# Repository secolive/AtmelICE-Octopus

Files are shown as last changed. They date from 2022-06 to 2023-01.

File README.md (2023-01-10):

"Octopus" adapter for Atmel-ICE
===============================

Introduction
------------

this project provides KiCad files for the implementation of an adapter board for use with the Atmel-ICE JTAG debugger.
It provides the following features:

- 0.1" headers with standard pinouts
- Specific VCCIO connector for using a probe
- Jumpers to select VCCIO from the appropriate connectors depending on the use case
- VCCIO comparator and limiter for current nominal voltages: 1.8V, 2.5V, 3.0V, 3.3V, 3.7V, 5.0V
- Voltage boosting to power the LEDs when VCCIO voltages below 3.3V are used

### Motivation

The Atmel-ICE provides two 0.05" headers, for which it's unfortunately difficult to get the appropriate cables. Some
versions of the Atmel-ICE come with a "squid" adapter, but are significantly more expensive.

Boards
------

This project contains two different boards that will assemble and work together as a single "product":

- ATMEL-ICE-Octopus: this is the main adapter board, including all circuits implementing VCCIO selection and limiting

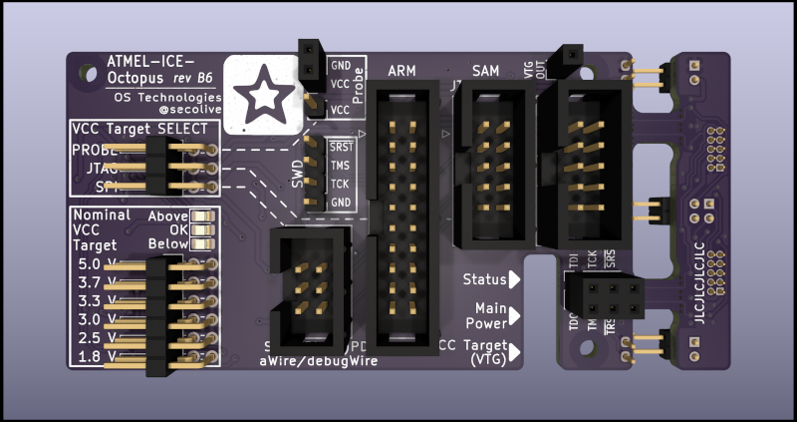
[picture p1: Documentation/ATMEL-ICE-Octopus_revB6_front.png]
Octopus front view
  
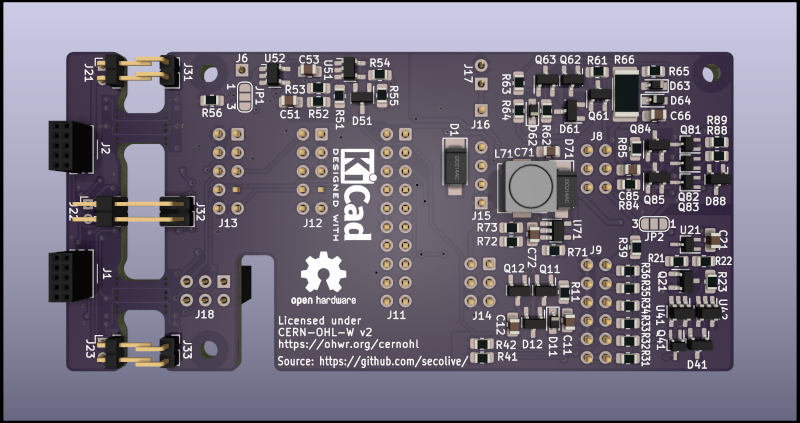
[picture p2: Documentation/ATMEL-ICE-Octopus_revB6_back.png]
Octopus front view
  

- JTAG-MINI_ADAPTER: 0.1" to 0.05" adapter for standard 10-pin JTAG connectors

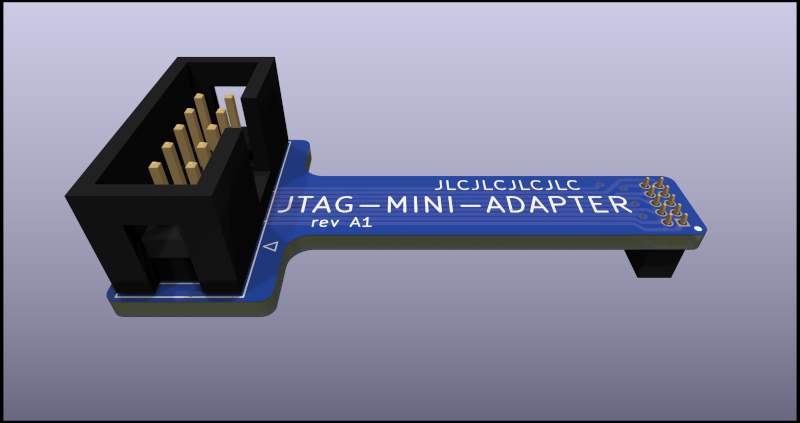
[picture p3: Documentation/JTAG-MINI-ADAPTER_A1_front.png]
JTAG Mini Adapter
  

Connectors
----------

The following connectors are provided by the Octopus:
- J11: 20-pin 0.1" Multi-ICE JTAG header
- J12: 10-pin 0.1" JTAG connector for ARM
- J13: 10-pin 0.1" JTAG connector for Atmel AVR
- J14: 6-pin 0.1" connector for misc AVR protocols: SPI, debugWire, aWire, PDI, UPDI, TPI
- J15: 4-pin 0.1" header matching Arduino's SWD port
- J16: 1-pin 0.1" header to use as VCCIO probe, typically in conjunction with J15 which does not provide any VCCIO;
  note that J15&J16 together work as a 6-pin 0.1" header combining SWD with VCCIO probe
- J17: 2-pin 0.1" socket to be used for adhoc connections
- J18: 6-pin 0.1" socket to be used for adhoc connections
- J6: 1-pin 0.1" socket to be used as a test point for the VTG provided to Atmel-ICE

VCCIO
-----

The Atmel-ICE needs to be fed with the VCCIO corresponding to the board under test, so that it will work at the same
logic level as the CPU being inspected.

To avoid damage to your CPU, it is important that the VCCIO that the Atmel-ICE uses does not exceed the level actually
used by the board. The octopus helps providing safety as follows:

- The reference VCCIO voltage can come from one of three sources, depending on your use case; these sources are: the
  JTAG connectors, the AVR misc connector, and the VCCIO probe. Use the appropriate source depending in your use case
  to ensure that you're using the VCCIO that matches the component you're connecting to.

- Select the appropriate source using the corresponding jumper; common use cases are:
    * when using a JTAG cable: put the jumper in the JTAG position;
    * when using the AVR misc cable, and your board runs on 5.0V: put the jumper in the SPI position;
    * when using the AVR misc cable, and your board runs on something else than 5.0V: put the jumper in the PROBE
      position, and use the PROBE connector in addition to the SPI cable;
    * when using the SWD cable: put the jumper in the PROBE position, and use the PROBE connector in addition to the SPI
      cable.

- You need to further configure the nominal voltage you're expecting to use with your device, using the appropriate
  jumper. The on-board detection logic will use this configuration to decide whether it is safe to propagate the VCCIO
  voltage to the Atmel-ICE VTG input, as follows:
    * if the input VCCIO matches the nominal voltage range, it is send to the Atmel-ICE, and the green "OK" LED will
      be lit;
    * if the input VCCIO is below the nominal voltage range, it is send to the Atmel-ICE nevertheless, but the amber
      "Below" LED will be lit;
    * otherwise, i.e. if the input VCCIO is above the nominal voltage range, no voltage is sent to the Atmel-ICE, because
      it is considered as a fault which could result in using a voltage higher than the expected VCCIO of the target
      device. In this case, the red "Above" LED will be lit.

Simplified Variants
-------------------

Depending on your use cases, you might not need all the features of the board; for example, perhaps you  need only the
various 0.1" connectors, but don't care about the voltage limiting. Reducing the feature set enables you to skip some
components and hence reduce the cost. Three features are optional:

- VCCIO monitoring and limiting; this main feature can by bypassed altogether, and the selected VCCIO can be sent
  directly as VTG to the Atmel-ICE. You will then have to ensure that you select the proper VCCIO signal, and that it
  does not exceed the target device voltage.

- Status output of the VCCIO monitoring and limiting; obviously, if you don't perform any monitoring and limiting, you
  won't need any status LEDs. Note that it's technically possible to have some voltage monitoring, without limiting,
  meaning VCCIO will always be sent as VTG to the Atmel-ICE, but the Above/OK/Below LEDs will still indicate whether the
  voltage is in the intended range.

- Voltage boosting to power LEDs when input voltage is below 3.3V. Obviously, if you don't want any status LEDs, you
  don't need any voltage boosting.

Altogether, this means the following variants are possible:

- Variant 1a: VCCIO limiting, monitoring with LEDS, voltage boosting
- Variant 1b: VCCIO limiting, monitoring with LEDS, no voltage boosting
- Variant 2a: VCCIO monitoring with LEDs, no limiting, voltage boosting
- Variant 2b: VCCIO monitoring with LEDs, no limiting, no voltage boosting
- Variant 3: VCCIO limiting, no monitoring, no LEDs
- Variant 4: no VCCIO limiting, no monitoring, no LEDs

The following table describes, for which variant, which components can be skipped, and how to position the solder
jumpers JP1 and JP2.

| Variant | *10-*39 | *40-*49 | *50-*59 | *60-*79 | *80-*89 | JP1 2-3 | JP2 2-3 |
|---|---|---|---|---|---|---|---|
| 1a | | | | | | | |
| 1b | | | |  skip | | | X |
| 2a | skip Q12, C12 | |  skip | | | X | |
| 2b | skip Q12, C12 | |  skip |  skip | | X | X |
| 3 | | skip Q41, R41, *42 | |  skip |  skip | | |
| 4 | skip | skip |  skip |  skip |  skip | X | |

Note that wildcards are used to designate any component with the given number, and when ranges are provided, any
component of any type within the given number range should be skipped. The JP columns indicate when the corresponding
jumper needs to have its pads 2 and 3 bridged.

Regarding JP1 and JP2, note that by default they are always bridged in the 1-2 position. It is not necessary to cut this
traced bridging, as long as the corresponding components are skipped according to the table above.

!! Do not forget to verify the proper jumper settings when adding new components to the board, e.g. in a later stage !!

Assembling
----------

The main board is composed of two different parts; when looking at the front:
- the right-hand side contains the black plate, which is meant to be connected to the Atmel-ICE
- the main part is the squid adapter itself

The back plate can be separated from the main part by breaking off the two break tabs. Connect the back plate to the 
main plate using angled 2mm-pitch headers. 

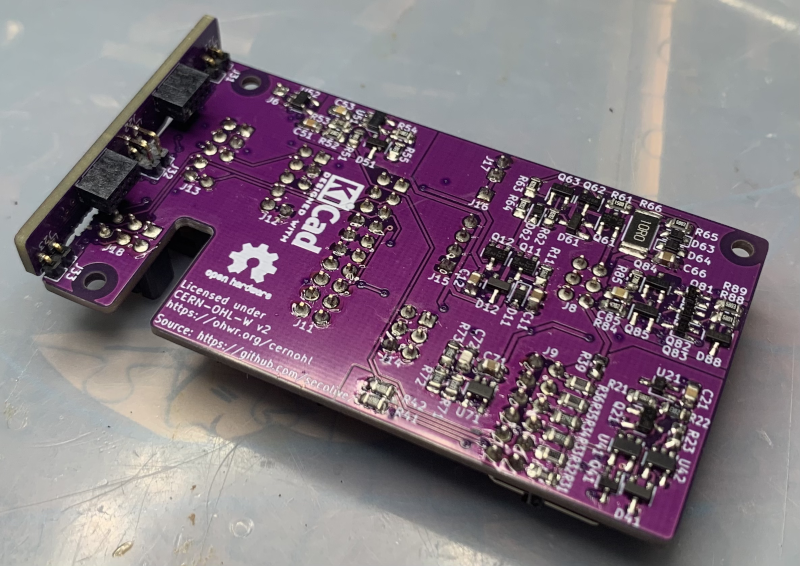
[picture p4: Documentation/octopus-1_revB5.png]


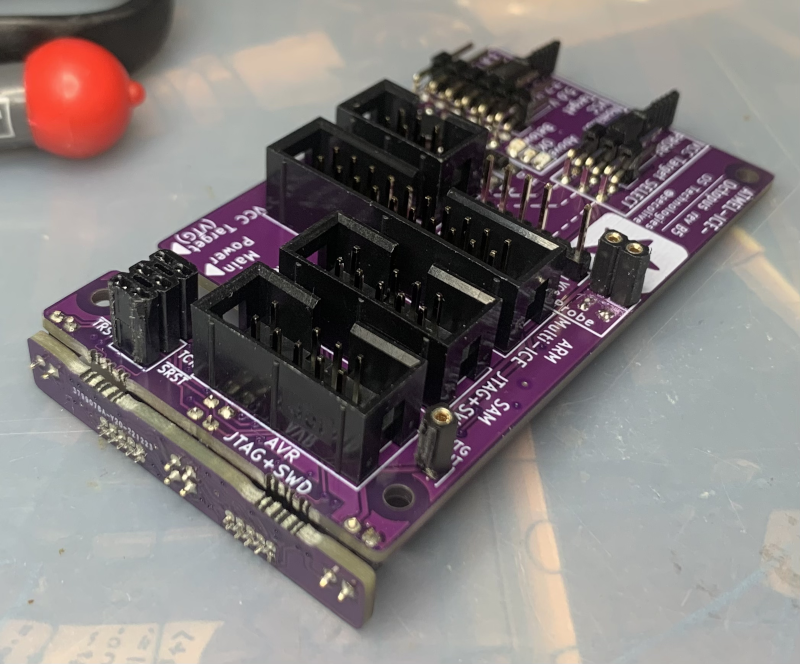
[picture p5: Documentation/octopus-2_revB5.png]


The assembled octopus adapter can then be plugged atop the Atmel-ICE; both products can be assembled using 8mm-long
spacers using M2.5 threads and screws (plastic recommended), as follows:

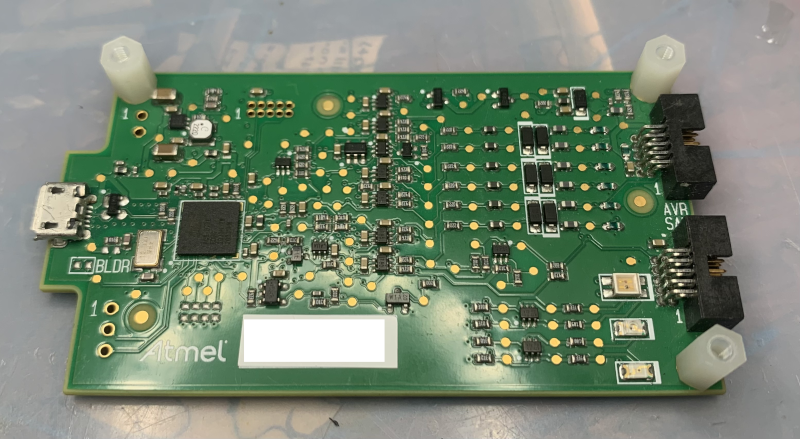
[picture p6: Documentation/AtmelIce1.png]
Atmel-ICE with M2.5x8mm spacers


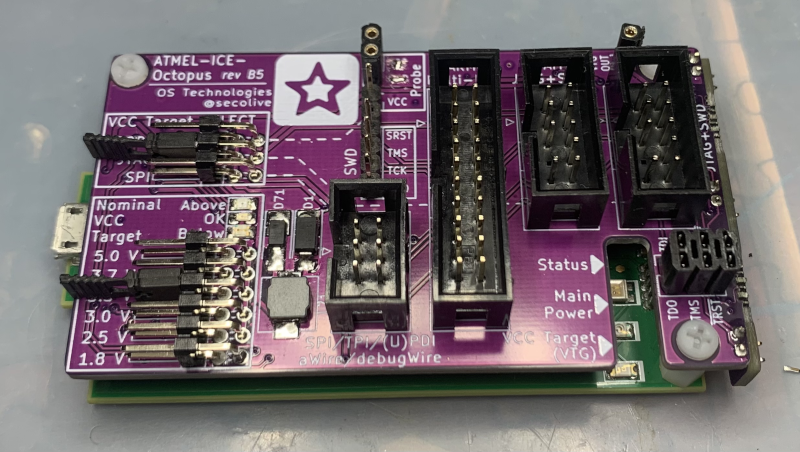
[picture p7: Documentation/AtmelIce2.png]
Atmel-ICE with Octopus installed


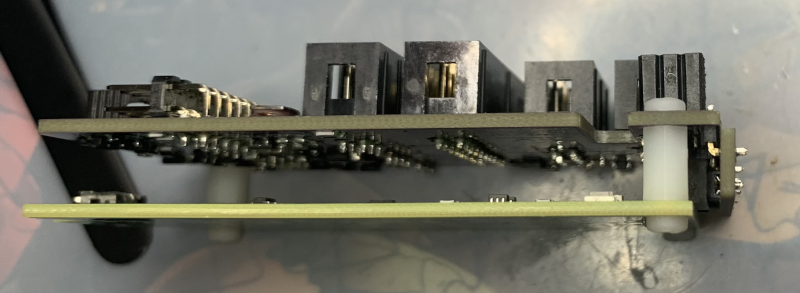
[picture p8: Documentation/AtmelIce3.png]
Atmel-ICE with Octopus installed


On the target device, use the adapter when using a standard Atmel 0.05" header; the adapter is designed to fit an
Arduino Due board and not collide with a shield, as follows:

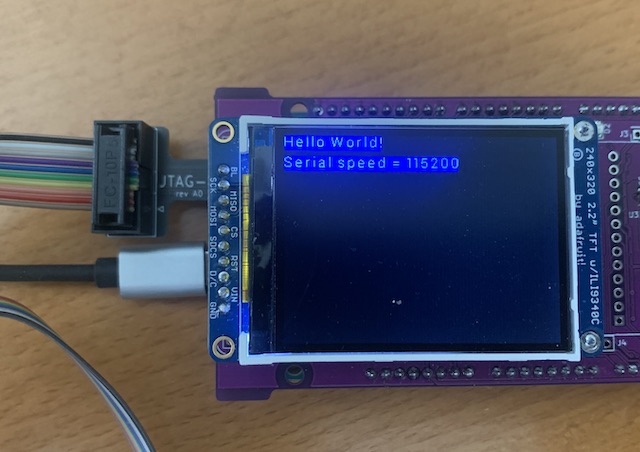
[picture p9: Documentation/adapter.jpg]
JTAG Adapter


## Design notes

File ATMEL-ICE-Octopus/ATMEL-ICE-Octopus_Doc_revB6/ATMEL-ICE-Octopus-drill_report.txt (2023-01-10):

Drill report for ATMEL-ICE-Octopus.kicad_pcb
Created on Monday, 09 January 2023 at 15:38:07

Copper Layer Stackup:
    =============================================================
    L1 :  F.Cu                      front
    L2 :  B.Cu                      back

Drill file 'ATMEL-ICE-Octopus.drl' contains
    plated through holes:
    =============================================================
    T1  0.400mm  0.0157"  (111 holes)
    T2  0.700mm  0.0276"  (20 holes)
    T3  0.800mm  0.0315"  (16 holes)
    T4  1.000mm  0.0394"  (76 holes)

    Total plated holes count 223

Not plated through holes are merged with plated holes
    unplated through holes:
    =============================================================
    T5  0.500mm  0.0197"  (24 holes)
    T6  2.500mm  0.0984"  (3 holes)

    Total unplated holes count 27

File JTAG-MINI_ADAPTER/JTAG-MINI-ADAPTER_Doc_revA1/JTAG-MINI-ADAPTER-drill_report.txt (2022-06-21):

Drill report for JTAG-MINI-ADAPTER.kicad_pcb
Created on Tuesday, 21 June 2022 at 16:49:53

Copper Layer Stackup:
    =============================================================
    L1 :  F.Cu                      front
    L2 :  B.Cu                      back

Drill file 'JTAG-MINI-ADAPTER.drl' contains
    plated through holes:
    =============================================================
    T1  0.400mm  0.0157"  (5 holes)
    T2  0.700mm  0.0276"  (10 holes)
    T3  1.000mm  0.0394"  (9 holes)

    Total plated holes count 24

Not plated through holes are merged with plated holes
    unplated through holes:
    =============================================================

    Total unplated holes count 0

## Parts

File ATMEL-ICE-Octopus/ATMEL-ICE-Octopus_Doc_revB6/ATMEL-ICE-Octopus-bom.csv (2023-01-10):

Row | Part | Footprint | Value | References | Quantity Per PCB | Description | Status
1 | C_Small | C_0805_2012Metric_Pad1.18x1.45mm_HandSolder | 10 pF | C72 | 1 | Unpolarized capacitor, small symbol
2 | C_Small | C_0805_2012Metric_Pad1.18x1.45mm_HandSolder | 1 nF | C53 C85 | 2 | Unpolarized capacitor, small symbol
3 | C_Small | C_0805_2012Metric_Pad1.18x1.45mm_HandSolder | 2.2 nF | C21 | 1 | Unpolarized capacitor, small symbol
4 | C_Small | C_0805_2012Metric_Pad1.18x1.45mm_HandSolder | 33 nF | C51 | 1 | Unpolarized capacitor, small symbol
5 | C_Small | C_0805_2012Metric_Pad1.18x1.45mm_HandSolder | 1 µF | C11 C66 C71 | 3 | Unpolarized capacitor, small symbol
6 | C_Small | C_0805_2012Metric_Pad1.18x1.45mm_HandSolder | 2.2 µF | C12 | 1 | Unpolarized capacitor, small symbol
7 | LED | LED_0805_2012Metric_Pad1.15x1.40mm_HandSolder | AMBER | D83 | 1 | Light emitting diode
8 | BAT54A | SOT-23_Handsoldering | BAT54A | D88 | 1 | schottky barrier diode
9 | BAT54C | SOT-23_Handsoldering | BAT54C | D12 D41 D51 | 3 | dual schottky barrier diode, common cathode
10 | BAT54S | SOT-23_Handsoldering | BAT54S | D61 | 1 | schottky barrier diode
11 | LED | LED_0805_2012Metric_Pad1.15x1.40mm_HandSolder | GREEN | D82 | 1 | Light emitting diode
12 | Zener_SOD323 | D_SOD-323_HandSoldering | PZU5.6B2A | D11 D62 D63 D64 | 4 | Zener diode
13 | LED | LED_0805_2012Metric_Pad1.15x1.40mm_HandSolder | RED | D81 | 1 | Light emitting diode
14 | D | D_SMA+SMP_Handsoldering | SMAJ13A | D1 | 1 | Diode
15 | D_Schottky | D_SMA+SMP_Handsoldering | SS13 | D71 | 1 | Schottky diode
16 | Conn_01x01_Female | PinSocket_1x01_P2.54mm_Vertical | Conn_01x01_Female | J6 | 1 | Generic connector, single row, 01x01, script generated (kicad-library-utils/schlib/autogen/connector/)
17 | Conn_01x02 | PinHeader_1x02_P2.00mm_Horizontal | Conn_01x02_Angled | J21 J23 | 2 | Generic connector, single row, 01x02, script generated (kicad-library-utils/schlib/autogen/connector/)
18 | Conn_01x02 | PinHeader_1x02_P2.00mm_Angled | Conn_01x02_Angled | J31 J33 | 2 | Generic connector, single row, 01x02, script generated (kicad-library-utils/schlib/autogen/connector/)
19 | Conn_01x02_Female | PinSocket_1x02_P2.54mm_Vertical | Conn_01x02_Female | J17 | 1 | Generic connector, single row, 01x02, script generated (kicad-library-utils/schlib/autogen/connector/)
20 | Conn_01x04 | PinHeader_2x02_P2.00mm_Horizontal | Conn_02x02_Angled | J22 | 1 | Generic connector, single row, 01x04, script generated (kicad-library-utils/schlib/autogen/connector/)
21 | Conn_01x04 | PinHeader_2x02_P2.00mm_Angled | Conn_02x02_Angled | J32 | 1 | Generic connector, single row, 01x04, script generated (kicad-library-utils/schlib/autogen/connector/)
22 | Conn_01x01 | PinHeader_1x01_P2.54mm_Vertical | conn_01x01 | J16 | 1 | Generic connector, single row, 01x01, script generated (kicad-library-utils/schlib/autogen/connector/)
23 | Conn_01x04 | PinHeader_1x04_P2.54mm_Vertical | conn_01x04 | J15 | 1 | Generic connector, single row, 01x04, script generated (kicad-library-utils/schlib/autogen/connector/)
24 | Conn_02x03_Odd_Even | IDC-Header_2x03_P2.54mm_Vertical | conn_02x03 | J14 | 1 | Generic connector, double row, 02x03, odd/even pin numbering scheme (row 1 odd numbers, row 2 even numbers), script generated (kicad-library-utils/schlib/autogen/connector/)
25 | Conn_02x03_Odd_Even | PinSocket_2x03_P2.54mm_Vertical | conn_02x03_Female | J18 | 1 | Generic connector, double row, 02x03, odd/even pin numbering scheme (row 1 odd numbers, row 2 even numbers), script generated (kicad-library-utils/schlib/autogen/connector/)
26 | Conn_02x05_Odd_Even | PinSocket_2x05_P1.27mm_Vertical_AtmelICE_WithTab | conn_02x05 | J1 J2 | 2 | Generic connector, double row, 02x05, odd/even pin numbering scheme (row 1 odd numbers, row 2 even numbers), script generated (kicad-library-utils/schlib/autogen/connector/)
27 | Conn_JTAG_02x05 | IDC-Header_2x05_P2.54mm_Vertical_Key7 | conn_02x05_key7 | J12 J13 | 2 | Generic connector, double row, 02x05, odd/even pin numbering scheme (row 1 odd numbers, row 2 even numbers), script generated (kicad-library-utils/schlib/autogen/connector/)
28 | Conn_02x10_Odd_Even | IDC-Header_2x10_P2.54mm_Vertical | conn_02x10 | J11 | 1 | Generic connector, double row, 02x10, odd/even pin numbering scheme (row 1 odd numbers, row 2 even numbers), script generated (kicad-library-utils/schlib/autogen/connector/)
29 | Conn_02x03_Odd_Even | PinHeader_2x03_P2.54mm_Horizontal_Jumper | ~ | J8 | 1 | Generic connector, double row, 02x03, odd/even pin numbering scheme (row 1 odd numbers, row 2 even numbers), script generated (kicad-library-utils/schlib/autogen/connector/)
30 | Conn_02x06_Odd_Even | PinHeader_2x06_P2.54mm_Horizontal_Jumper | ~ | J9 | 1 | Generic connector, double row, 02x06, odd/even pin numbering scheme (row 1 odd numbers, row 2 even numbers), script generated (kicad-library-utils/schlib/autogen/connector/)
31 | L_Small | L_6.5x6.5_H4.5 | LQH5BPN100MT0L | L71 | 1 | Inductor, small symbol
32 | 2SK2394 | SOT-23_Handsoldering | 2SK2394 | Q21 | 1 | N-JFET transistor, 15 V, 10 to 20 mA, 38 mS, -0.3 to -1.0 Vgs(off), SOT23-3
33 | BC857B | SOT-23_Handsoldering | BC857B | Q63 Q84 Q85 | 3 | 500mA Ic, 60V Vce, PNP Transistor, SOT-23
34 | CPH3910 | SOT-23_Handsoldering | CPH3910 | Q11 Q12 Q61 | 3 | N-JFET transistor, 25 V, 20 to 40 mA, 40 mS, -0.6 to -1.8 Vgs(off), SOT23-3
35 | NX6008NBKW | SOT-323_SC-70_Handsoldering | NX6008NBKW | Q41 Q81 Q82 Q83 | 4 | 60V Vds, 0.9V Vgs(th) max, 250mA Id, N-Channel MOSFET, SOT-323
36 | NXV100XP | SOT-23_Handsoldering | NXV100XP | Q62 | 1 | P-channel MOSFET -30V, -1.5A
37 | R | R_2512_6332Metric_Pad1.40x3.35mm_HandSolder | 10 Ω | R66 | 1 | Resistor
38 | R | R_0805_2012Metric_Pad1.20x1.40mm_HandSolder | 150 Ω | R61 | 1 | Resistor
39 | R | R_0805_2012Metric_Pad1.20x1.40mm_HandSolder | 280 Ω | R85 | 1 | Resistor
40 | R | R_0805_2012Metric_Pad1.20x1.40mm_HandSolder | 560 Ω | R11 | 1 | Resistor
41 | R | R_0805_2012Metric_Pad1.20x1.40mm_HandSolder | 6.8 kΩ | R21 R88 | 2 | Resistor
42 | R | R_0805_2012Metric_Pad1.20x1.40mm_HandSolder | 13 kΩ | R22 | 1 | Resistor
43 | R | R_0805_2012Metric_Pad1.20x1.40mm_HandSolder | 17.4 kΩ | R36 | 1 | Resistor
44 | R | R_0805_2012Metric_Pad1.20x1.40mm_HandSolder | 30.1 kΩ | R35 | 1 | Resistor
45 | R | R_0805_2012Metric_Pad1.20x1.40mm_HandSolder | 33 kΩ | R52 | 1 | Resistor
46 | R | R_0805_2012Metric_Pad1.20x1.40mm_HandSolder | 37.4 kΩ | R34 | 1 | Resistor
47 | R | R_0805_2012Metric_Pad1.20x1.40mm_HandSolder | 39 kΩ | R73 | 1 | Resistor
48 | R | R_0805_2012Metric_Pad1.20x1.40mm_HandSolder | 47 kΩ | R41 R42 R84 | 3 | Resistor
49 | R | R_0805_2012Metric_Pad1.20x1.40mm_HandSolder | 48.1 kΩ | R39 | 1 | Resistor
50 | R | R_0805_2012Metric_Pad1.20x1.40mm_HandSolder | 48.7 kΩ | R33 | 1 | Resistor
51 | R | R_0805_2012Metric_Pad1.20x1.40mm_HandSolder | 72.3 kΩ | R23 | 1 | Resistor
52 | R | R_0805_2012Metric_Pad1.20x1.40mm_HandSolder | 80.6 kΩ | R32 | 1 | Resistor
53 | R | R_0805_2012Metric_Pad1.20x1.40mm_HandSolder | 82 kΩ | R62 R63 R64 | 3 | Resistor
54 | R | R_0805_2012Metric_Pad1.20x1.40mm_HandSolder | 85.6 kΩ | R31 | 1 | Resistor
55 | R | R_0805_2012Metric_Pad1.20x1.40mm_HandSolder | 120 kΩ | R55 | 1 | Resistor
56 | R | R_0805_2012Metric_Pad1.20x1.40mm_HandSolder | 180 kΩ | R51 R54 | 2 | Resistor
57 | R | R_0805_2012Metric_Pad1.20x1.40mm_HandSolder | 220 kΩ | R71 | 1 | Resistor
58 | R | R_0805_2012Metric_Pad1.20x1.40mm_HandSolder | 330 kΩ | R72 | 1 | Resistor
59 | R | R_0805_2012Metric_Pad1.20x1.40mm_HandSolder | 390 kΩ | R53 | 1 | Resistor
60 | R | R_0805_2012Metric_Pad1.20x1.40mm_HandSolder | 680 kΩ | R65 R89 | 2 | Resistor
61 | R | R_0805_2012Metric_Pad1.20x1.40mm_HandSolder | 1 MΩ | R56 | 1 | Resistor
62 | AP2280-xW | SOT-23-5_HandSoldering | AP2280-xW | U52 | 1 | Current limited power switch, single channel, SOT-23-5
63 | AP3015A | SOT-23-5_HandSoldering | AP3015A | U71 | 1 | Micropower, Step-up, Switching Regulator, TSOT-23-5
64 | NCS2200SN2T1 | SOT-23-5_HandSoldering | NCS2200SN2T1 | U51 | 1 | Single General-Purpose Low-Voltage Comparator, SOT-23-5/SC-70-5
65 | NCS2202SN2T1 | SOT-23-5_HandSoldering | NCS2202SN2T1 | U41 U42 | 2 | Single General-Purpose Low-Voltage Comparator, SOT-23-5/SC-70-5
66 | TS4061BICT | SOT-323_SC-70_Handsoldering | TS4061BICT | U21 | 1 | Precision Micropower Shunt Voltage Reference, SOT-323
Project info:
Schematic: | ATMEL-ICE-Octopus
Variant: | default
Revision: | B6
Date: | 2023-01-09_14-09-04
KiCad Version: | (6.0.10-0)
Statistics:
Component Groups: | 66
Component Count: | 93
Fitted Components: | 93
Number of PCBs: | 1
Total Components: | 93

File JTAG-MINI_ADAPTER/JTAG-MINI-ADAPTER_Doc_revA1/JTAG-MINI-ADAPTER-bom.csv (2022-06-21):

Row | Part | Footprint | Value | References | Quantity Per PCB | Description | Status
1 | Conn_02x05_Odd_Even | PinSocket_2x05_P1.27mm_Vertical | ATMEL-ICE SAM SOCKET | J1 | 1 | Generic connector, double row, 02x05, odd/even pin numbering scheme (row 1 odd numbers, row 2 even numbers), script generated (kicad-library-utils/schlib/autogen/connector/)
2 | Conn_JTAG_02x05 | IDC-Header_2x05_P2.54mm_Vertical_Key7 | SWD/JTAG SAM (ARM/Cortex-M dbg) | J12 | 1 | Generic connector, double row, 02x05, odd/even pin numbering scheme (row 1 odd numbers, row 2 even numbers), script generated (kicad-library-utils/schlib/autogen/connector/)
Project info:
Schematic: | JTAG-MINI-ADAPTER
Variant: | default
Revision: | A1
Date: | 2022-06-21_16-45-29
KiCad Version: | (6.0.2-0)
Statistics:
Component Groups: | 2
Component Count: | 2
Fitted Components: | 2
Number of PCBs: | 1
Total Components: | 2

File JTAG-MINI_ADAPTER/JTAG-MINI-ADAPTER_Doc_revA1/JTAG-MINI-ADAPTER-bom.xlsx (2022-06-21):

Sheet: BoM
 |  | KiBot Bill of Materials
 |  | Schematic: | JTAG-MINI-ADAPTER | Component Groups: | 2
 |  | Variant: | default | Component Count: | 2
 |  | Revision: | A1 | Fitted Components: | 2
 |  | Date: | 2022-06-21_16-45-29 | Number of PCBs: | 1
 |  | KiCad Version: | (6.0.2-0) | Total Components: | 2
Row | Part | Footprint | Value | References | Quantity Per PCB | Description | Status
1 | Conn_02x05_Odd_Even | PinSocket_2x05_P1.27mm_Vertical | ATMEL-ICE SAM SOCKET | J1 | 1 | Generic connector, double row, 02x05, odd/even pin numbering scheme (row 1 odd numbers, row 2 even numbers), script generated (kicad-library-utils/schlib/autogen/connector/)
2 | Conn_JTAG_02x05 | IDC-Header_2x05_P2.54mm_Vertical_Key7 | SWD/JTAG SAM (ARM/Cortex-M dbg) | J12 | 1 | Generic connector, double row, 02x05, odd/even pin numbering scheme (row 1 odd numbers, row 2 even numbers), script generated (kicad-library-utils/schlib/autogen/connector/)

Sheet: Colors
KiCad Fields (default)
Generated Fields
User Fields
Empty Fields

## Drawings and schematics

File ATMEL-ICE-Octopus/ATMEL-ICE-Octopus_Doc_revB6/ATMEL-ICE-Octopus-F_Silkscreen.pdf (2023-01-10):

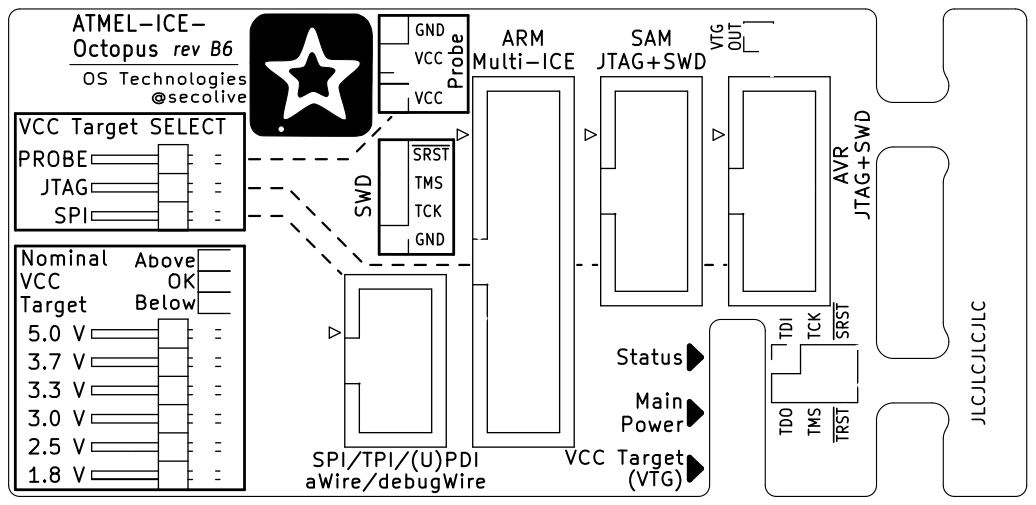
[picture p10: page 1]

SPI/TPI/(U)PDI aWire/debugWire Below

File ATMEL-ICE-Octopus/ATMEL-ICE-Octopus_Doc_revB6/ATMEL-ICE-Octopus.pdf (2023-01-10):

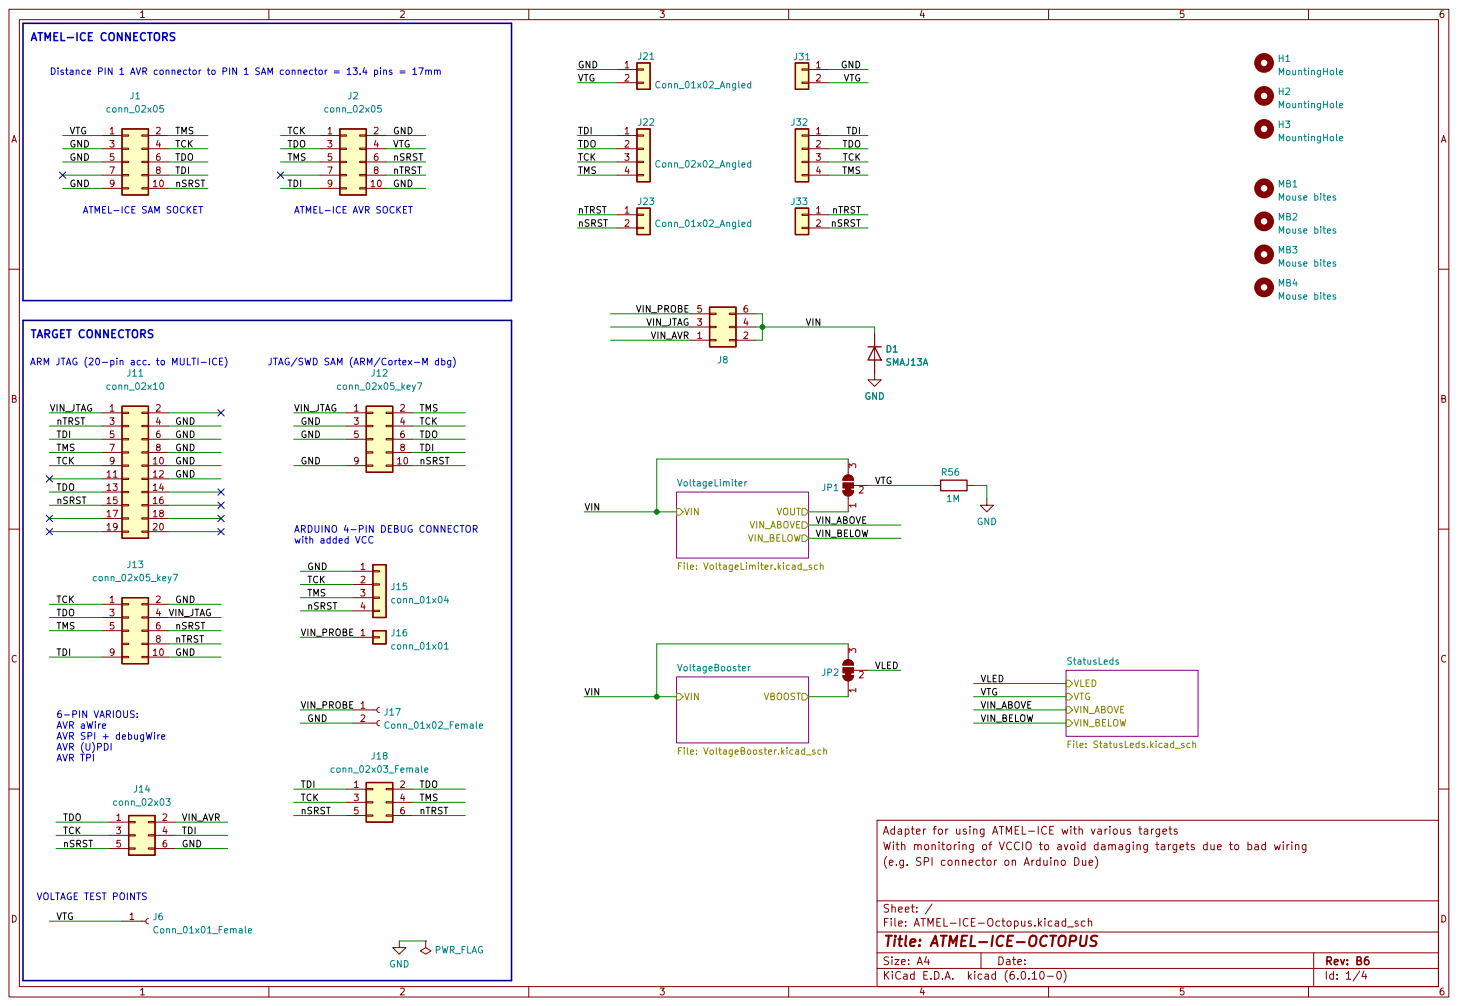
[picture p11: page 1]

Distance PIN 1 AVR connector to PIN 1 SAM connector = 13.4 pins = 17mm ATMEL-ICE SAM SOCKET TARGET CONNECTORS ATMEL-ICE CONNECTORS

ARM JTAG (20-pin acc. to MULTI-ICE) VOLTAGE TEST POINTS

ATMEL-ICE AVR SOCKET

TCK GND GND GND GND GND

ARDUINO 4-PIN DEBUG CONNECTOR
with added VCC

6-PIN VARIOUS: AVR aWire AVR SPI + debugWire

AVR (U)PDI AVR TPI

With monitoring of VCCIO to avoid damaging targets due to bad wiring
File: ATMEL-ICE-Octopus.kicad_sch Sheet: / (e.g. SPI connector on Arduino Due)

Id: 1/4 Title: ATMEL-ICE-OCTOPUS

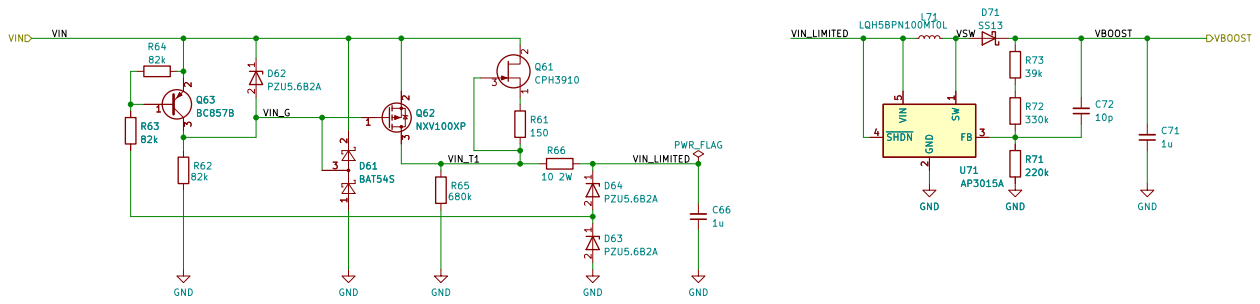
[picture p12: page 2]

5 U71 AP3015A GND GND GND GND

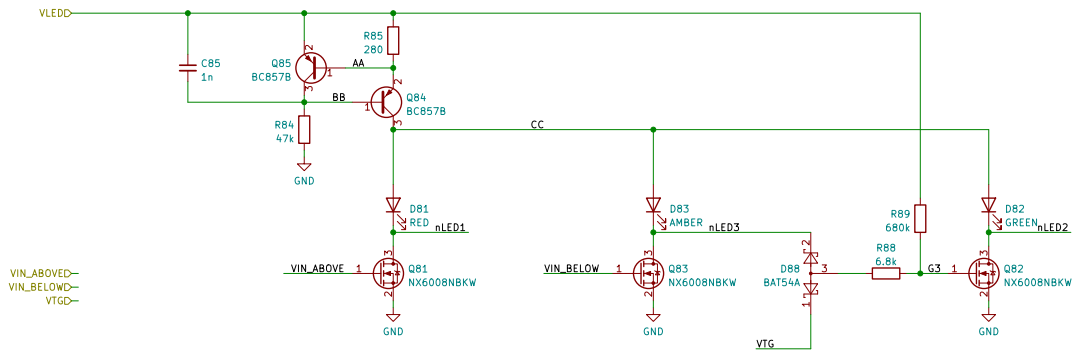
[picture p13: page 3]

File: StatusLeds.kicad_sch Sheet: /StatusLeds/ R88

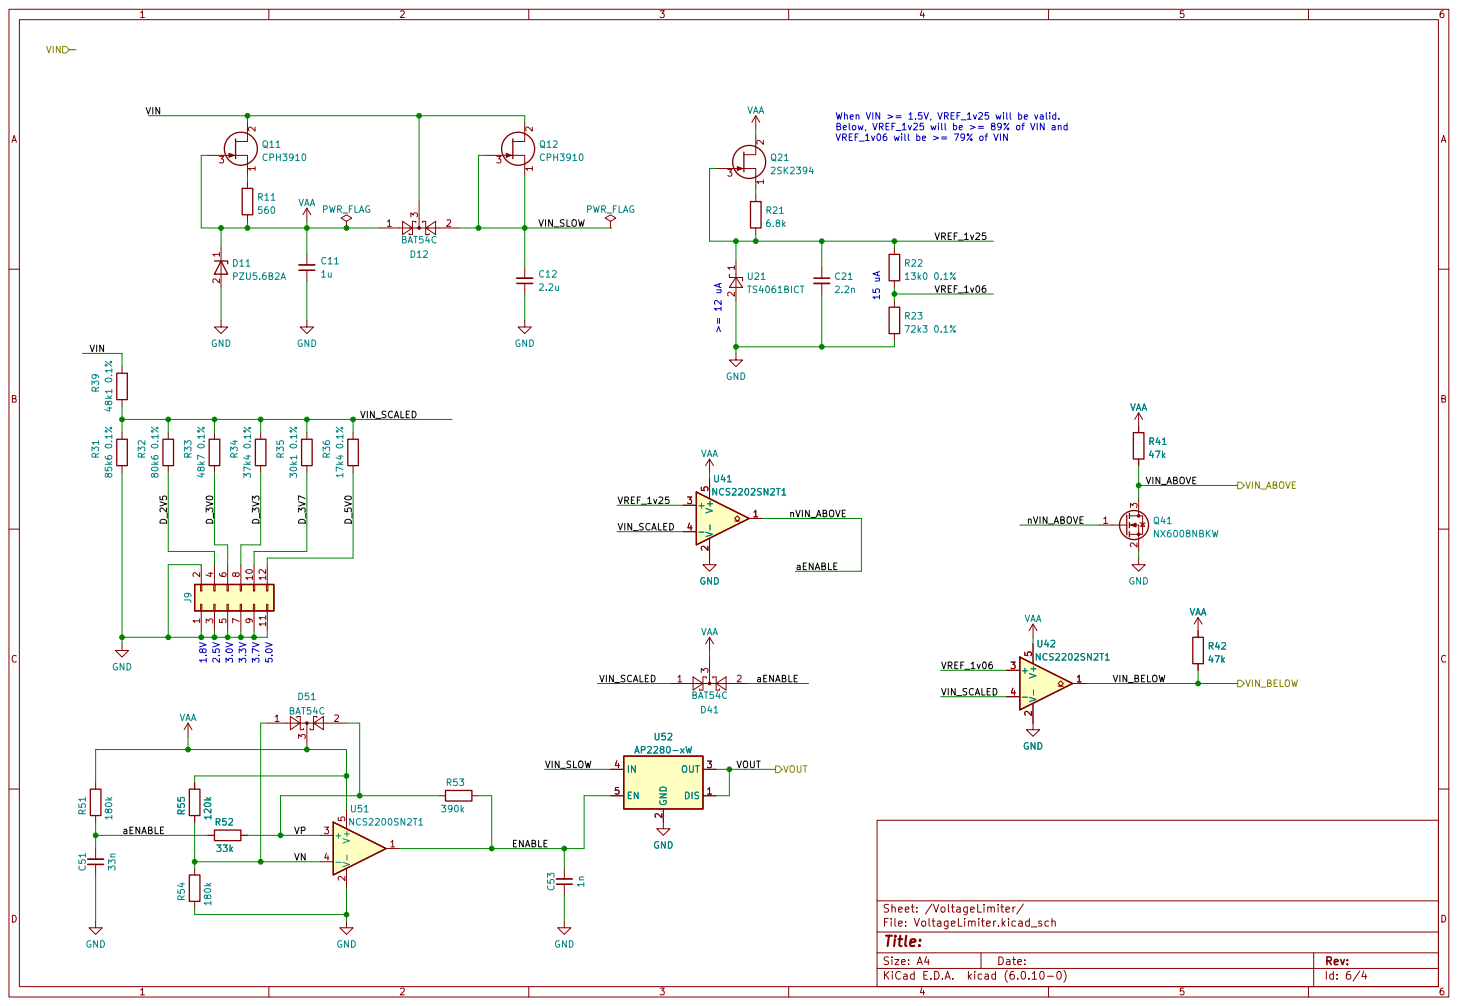
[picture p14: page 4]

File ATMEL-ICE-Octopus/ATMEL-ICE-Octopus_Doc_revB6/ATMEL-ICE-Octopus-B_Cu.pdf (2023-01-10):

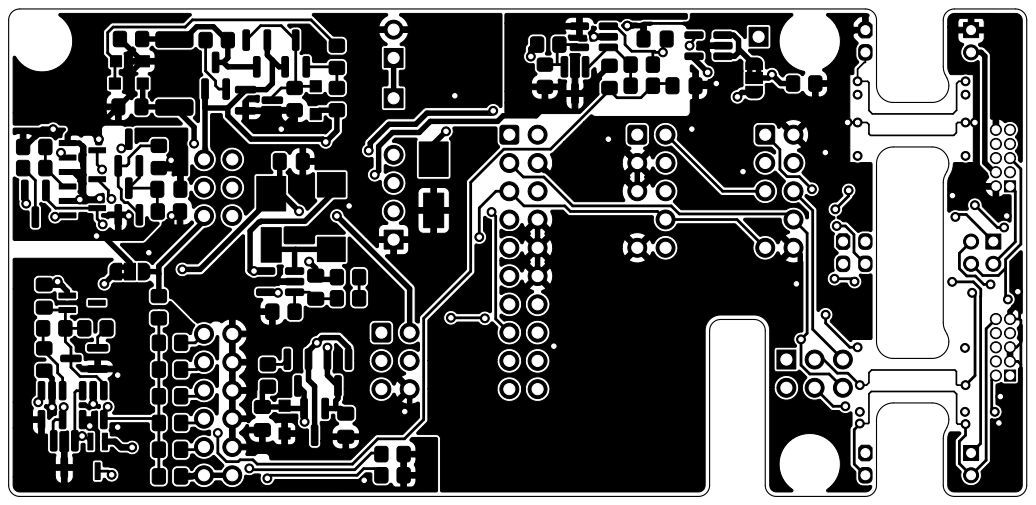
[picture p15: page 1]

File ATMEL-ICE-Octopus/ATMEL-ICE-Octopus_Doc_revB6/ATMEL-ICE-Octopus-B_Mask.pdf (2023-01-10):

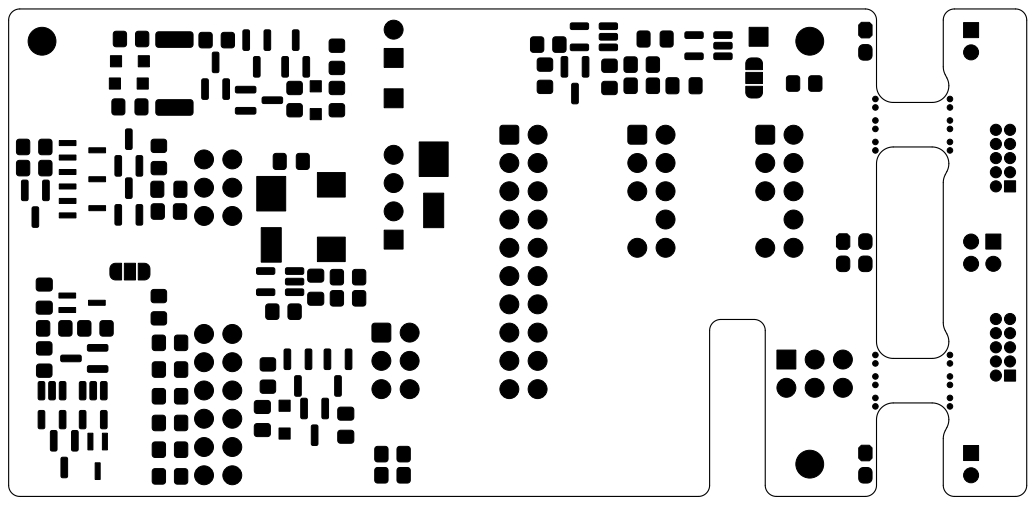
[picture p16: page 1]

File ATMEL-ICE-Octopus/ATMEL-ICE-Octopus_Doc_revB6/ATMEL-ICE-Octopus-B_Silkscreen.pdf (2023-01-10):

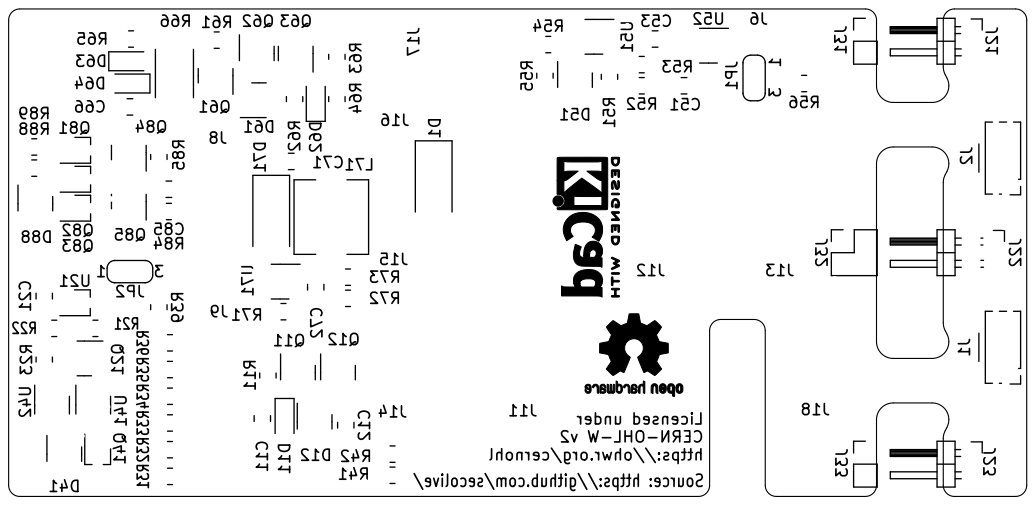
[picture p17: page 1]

Source: https://github.com/secolive/ Licensed under CERN-OHL-W v2 https://ohwr.org/cernohl J9

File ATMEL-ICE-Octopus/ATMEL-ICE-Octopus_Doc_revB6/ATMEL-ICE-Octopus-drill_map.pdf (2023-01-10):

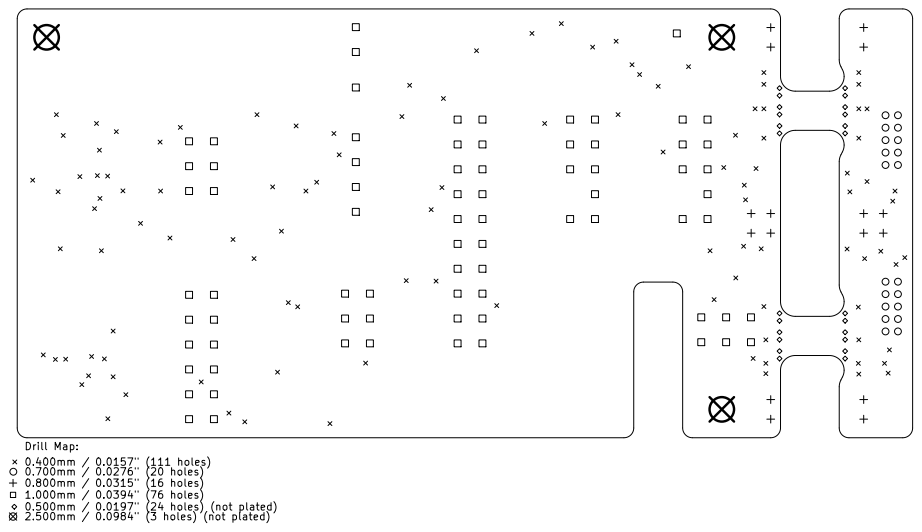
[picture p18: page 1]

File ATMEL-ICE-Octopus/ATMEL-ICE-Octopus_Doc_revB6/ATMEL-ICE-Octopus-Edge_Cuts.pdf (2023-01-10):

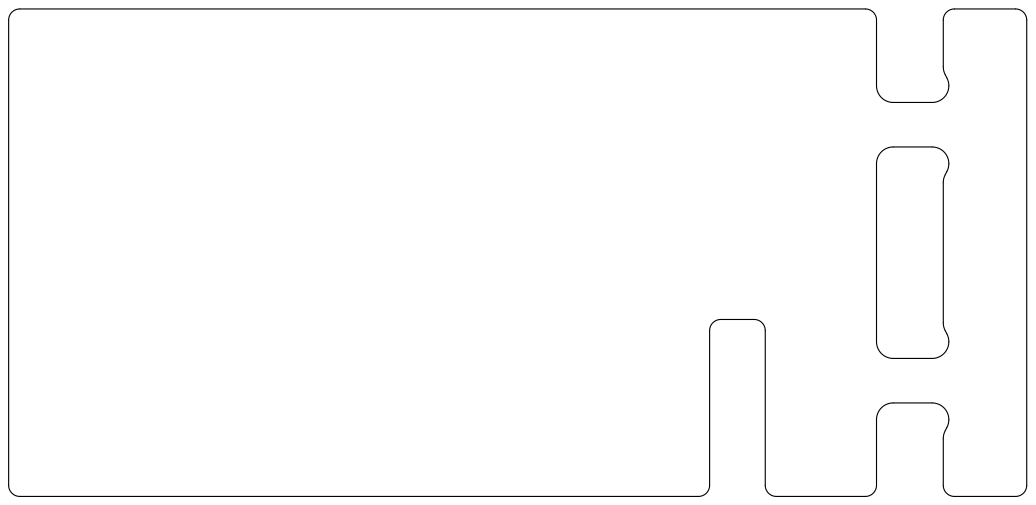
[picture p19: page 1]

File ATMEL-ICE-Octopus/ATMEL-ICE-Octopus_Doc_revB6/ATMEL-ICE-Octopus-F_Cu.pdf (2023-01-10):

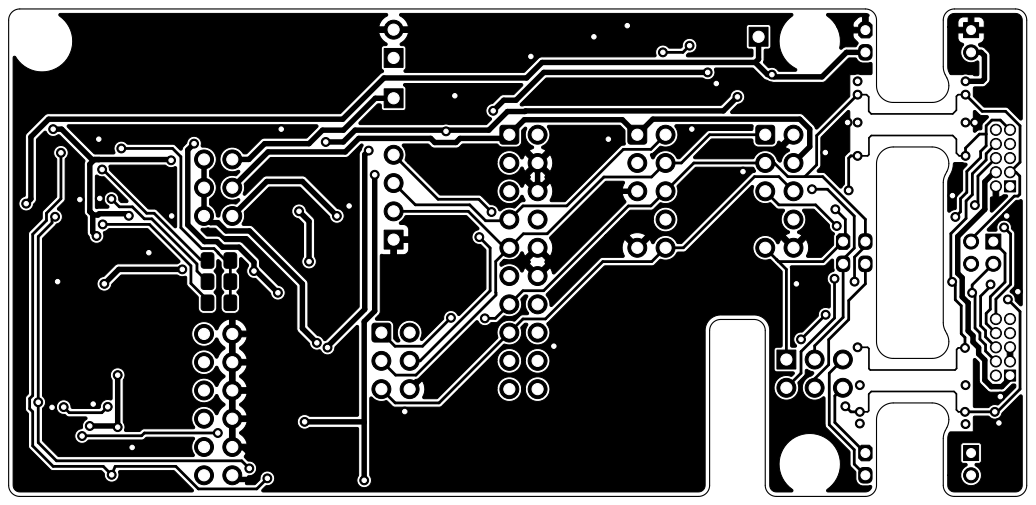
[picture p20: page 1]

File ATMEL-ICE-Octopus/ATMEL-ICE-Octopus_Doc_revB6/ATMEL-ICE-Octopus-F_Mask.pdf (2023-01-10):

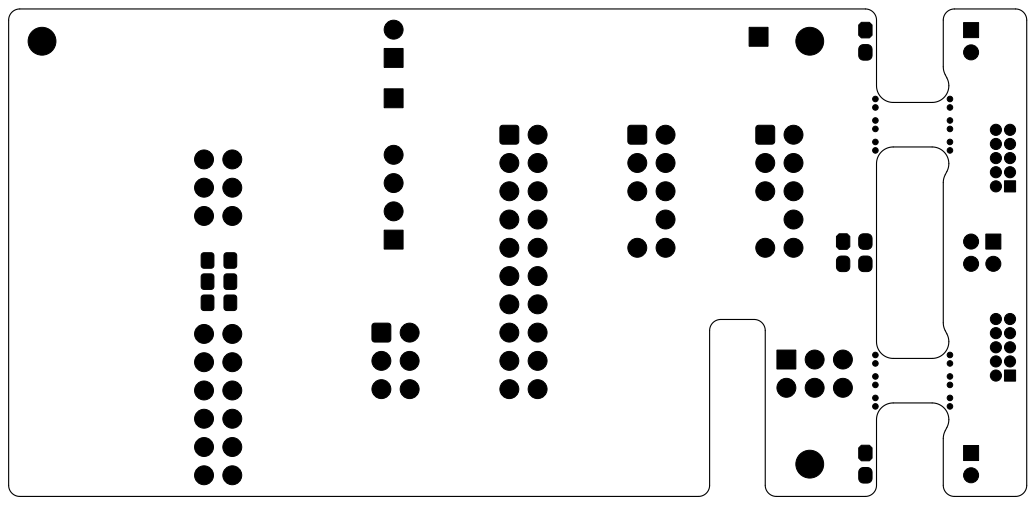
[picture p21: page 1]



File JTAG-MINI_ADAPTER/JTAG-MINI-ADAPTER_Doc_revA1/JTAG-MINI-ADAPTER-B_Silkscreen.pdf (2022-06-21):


Licensed under CERN-OHL-W v2

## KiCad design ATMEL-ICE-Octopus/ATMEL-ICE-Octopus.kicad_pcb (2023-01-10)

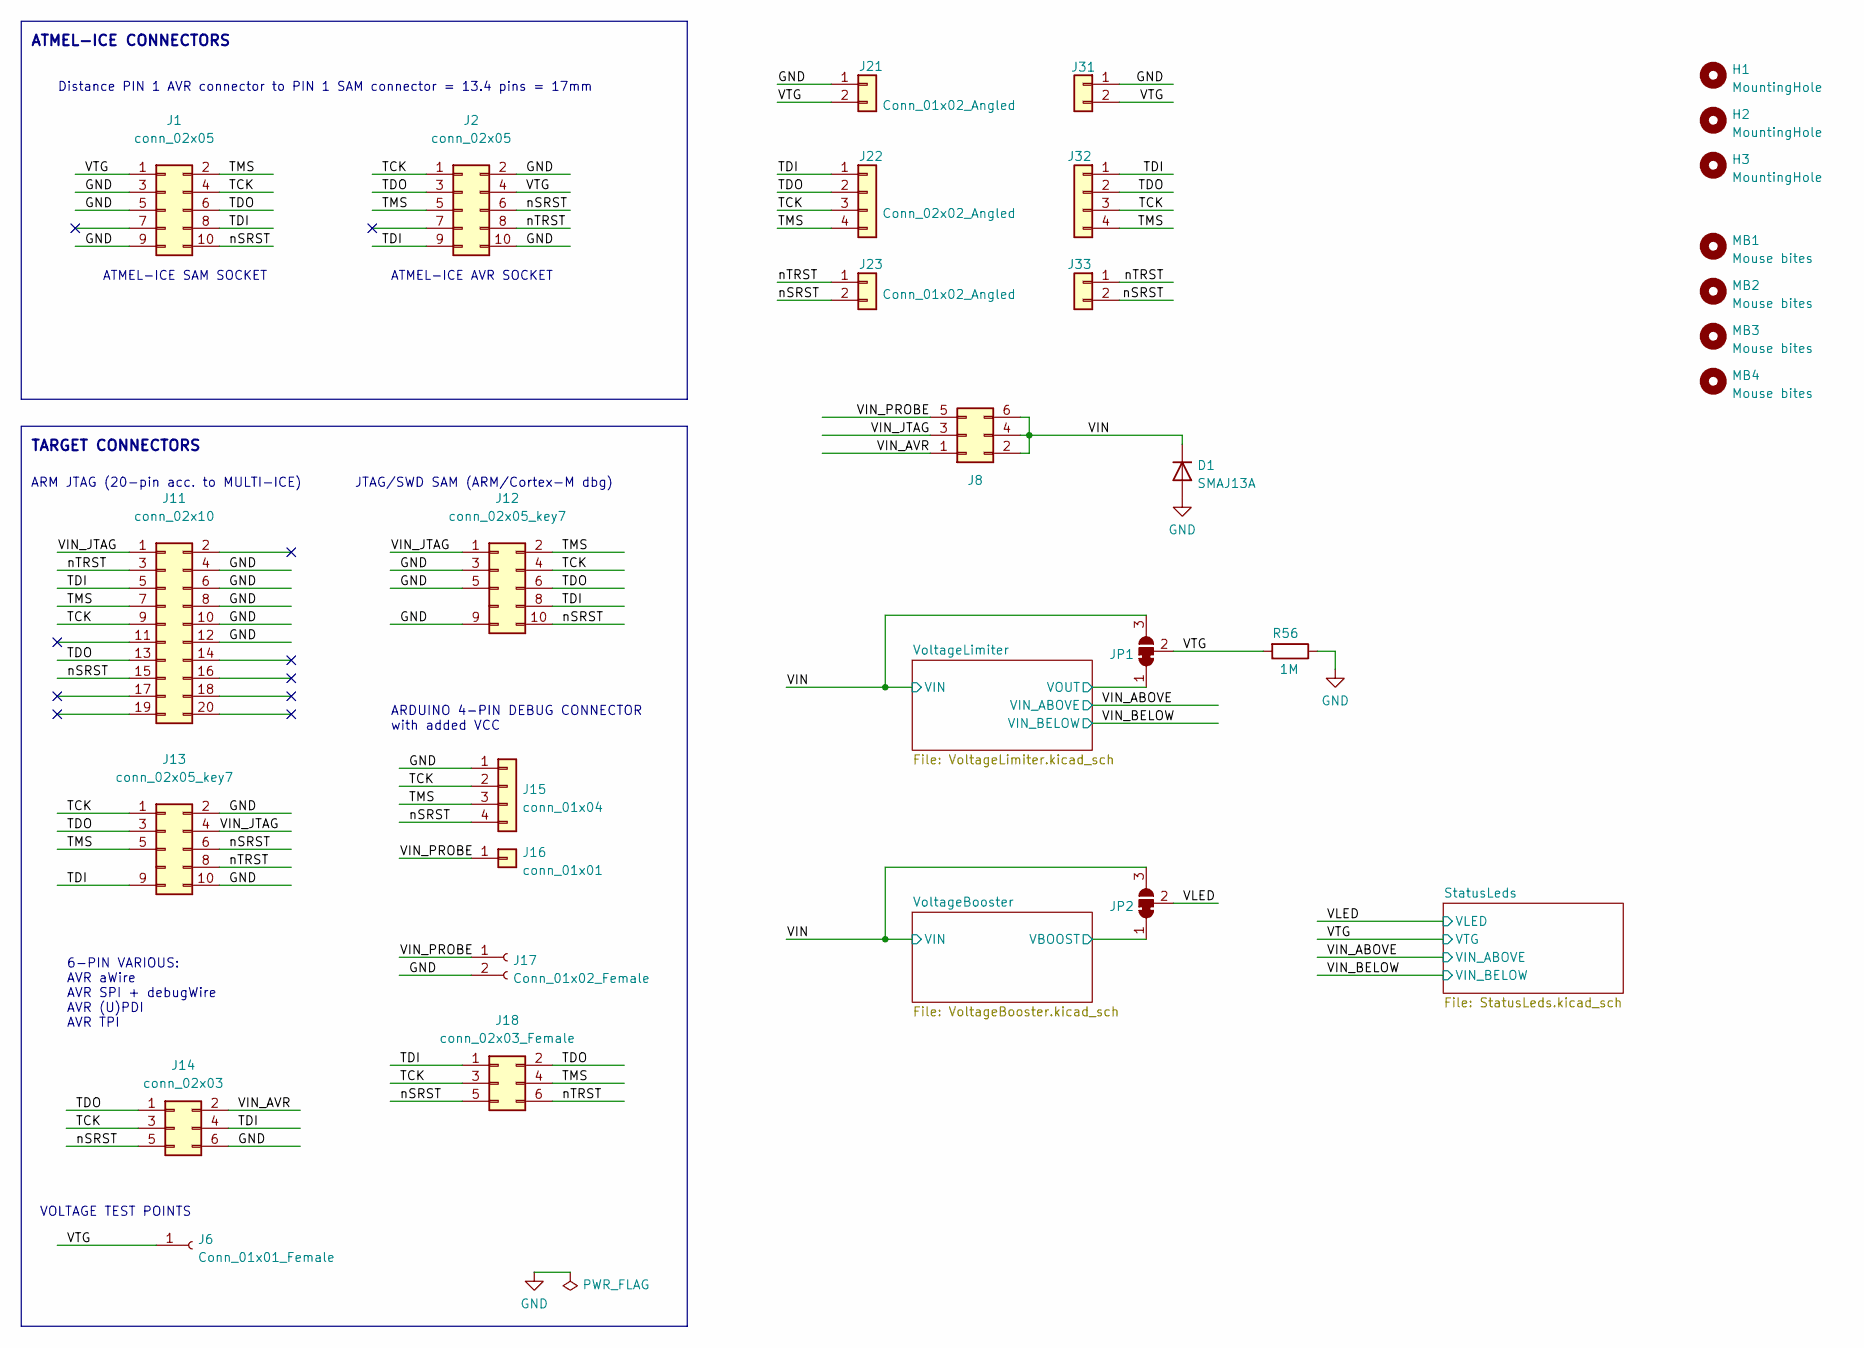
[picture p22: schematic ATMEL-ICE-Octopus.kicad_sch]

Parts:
D1: SMAJ13A; D_SMA+SMP_Handsoldering
H1, H2, H3: MountingHole; MountingHole_2.5mm
J1, J2: conn_02x05; PinSocket_2x05_P1.27mm_Vertical_AtmelICE_WithTab
J6: Conn_01x01_Female; PinSocket_1x01_P2.54mm_Vertical
J8: PinHeader_2x03_P2.54mm_Horizontal_Jumper
J11: conn_02x10; IDC-Header_2x10_P2.54mm_Vertical
J12, J13: conn_02x05_key7; IDC-Header_2x05_P2.54mm_Vertical_Key7
J14: conn_02x03; IDC-Header_2x03_P2.54mm_Vertical
J15: conn_01x04; PinHeader_1x04_P2.54mm_Vertical
J16: conn_01x01; PinHeader_1x01_P2.54mm_Vertical
J17: Conn_01x02_Female; PinSocket_1x02_P2.54mm_Vertical
J18: conn_02x03_Female; PinSocket_2x03_P2.54mm_Vertical
J21, J23: Conn_01x02_Angled; PinHeader_1x02_P2.00mm_Horizontal
J22: Conn_02x02_Angled; PinHeader_2x02_P2.00mm_Horizontal
J31, J33: Conn_01x02_Angled; PinHeader_1x02_P2.00mm_Angled
J32: Conn_02x02_Angled; PinHeader_2x02_P2.00mm_Angled
JP1, JP2: SolderJumper_3_Bridged12; SolderJumper-3_P1.3mm_Bridged2Bar12_RoundedPad1.0x1.5mm_Num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
MB1, MB2, MB3, MB4: Mouse bites; mouse-bite-3x4mm-slot
R56: 1M; R_0805_2012Metric_Pad1.20x1.40mm_HandSolder

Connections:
/TCK: J1.4, J2.1, J11.9, J12.4, J13.1, J14.3, J15.2, J18.3, J22.3, J32.3
/TDI: J1.8, J2.9, J11.5, J12.8, J13.9, J14.4, J18.1, J22.1, J32.1
/TDO: J1.6, J2.3, J11.13, J12.6, J13.3, J14.1, J18.2, J22.2, J32.2
/TMS: J1.2, J2.5, J11.7, J12.2, J13.5, J15.3, J18.4, J22.4, J32.4
/VIN: D1.1 (K), J8.2, J8.4, J8.6, JP1.3 (B), JP2.3 (B); also elsewhere on the board
/VIN_AVR: J8.1, J14.2
/VIN_JTAG: J8.3, J11.1, J12.1, J13.4
/VIN_PROBE: J8.5, J16.1, J17.1
/VLED: JP2.2 (C); also elsewhere on the board
/VTG: J1.1, J2.4, J6.1, J21.2, J31.2, JP1.2 (C), R56.2; also elsewhere on the board
/VoltageBooster/VBOOST: JP2.1 (A); also elsewhere on the board
/VoltageLimiter/VOUT: JP1.1 (A); also elsewhere on the board
/nSRST: J1.10, J2.6, J11.15, J12.10, J13.6, J14.5, J15.4, J18.5, J23.2, J33.2
/nTRST: J2.8, J11.3, J13.8, J18.6, J23.1, J33.1
GND: D1.2 (A), J1.3, J1.5, J1.9, J2.2, J2.10, J11.4, J11.6, J11.8, J11.10, J11.12, J12.3, J12.5, J12.9, J13.2, J13.10, J14.6, J15.1, J17.2, J21.1, J31.1, R56.1; also elsewhere on the board

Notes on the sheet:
ARDUINO 4-PIN DEBUG CONNECTOR with added VCC
Distance PIN 1 AVR connector to PIN 1 SAM connector = 13.4 pins = 17mm
6-PIN VARIOUS: AVR aWire AVR SPI + debugWire AVR (U)PDI AVR TPI
ARM JTAG (20-pin acc. to MULTI-ICE)
ATMEL-ICE CONNECTORS
ATMEL-ICE AVR SOCKET
VOLTAGE TEST POINTS
TARGET CONNECTORS
ATMEL-ICE SAM SOCKET
JTAG/SWD SAM (ARM/Cortex-M dbg)

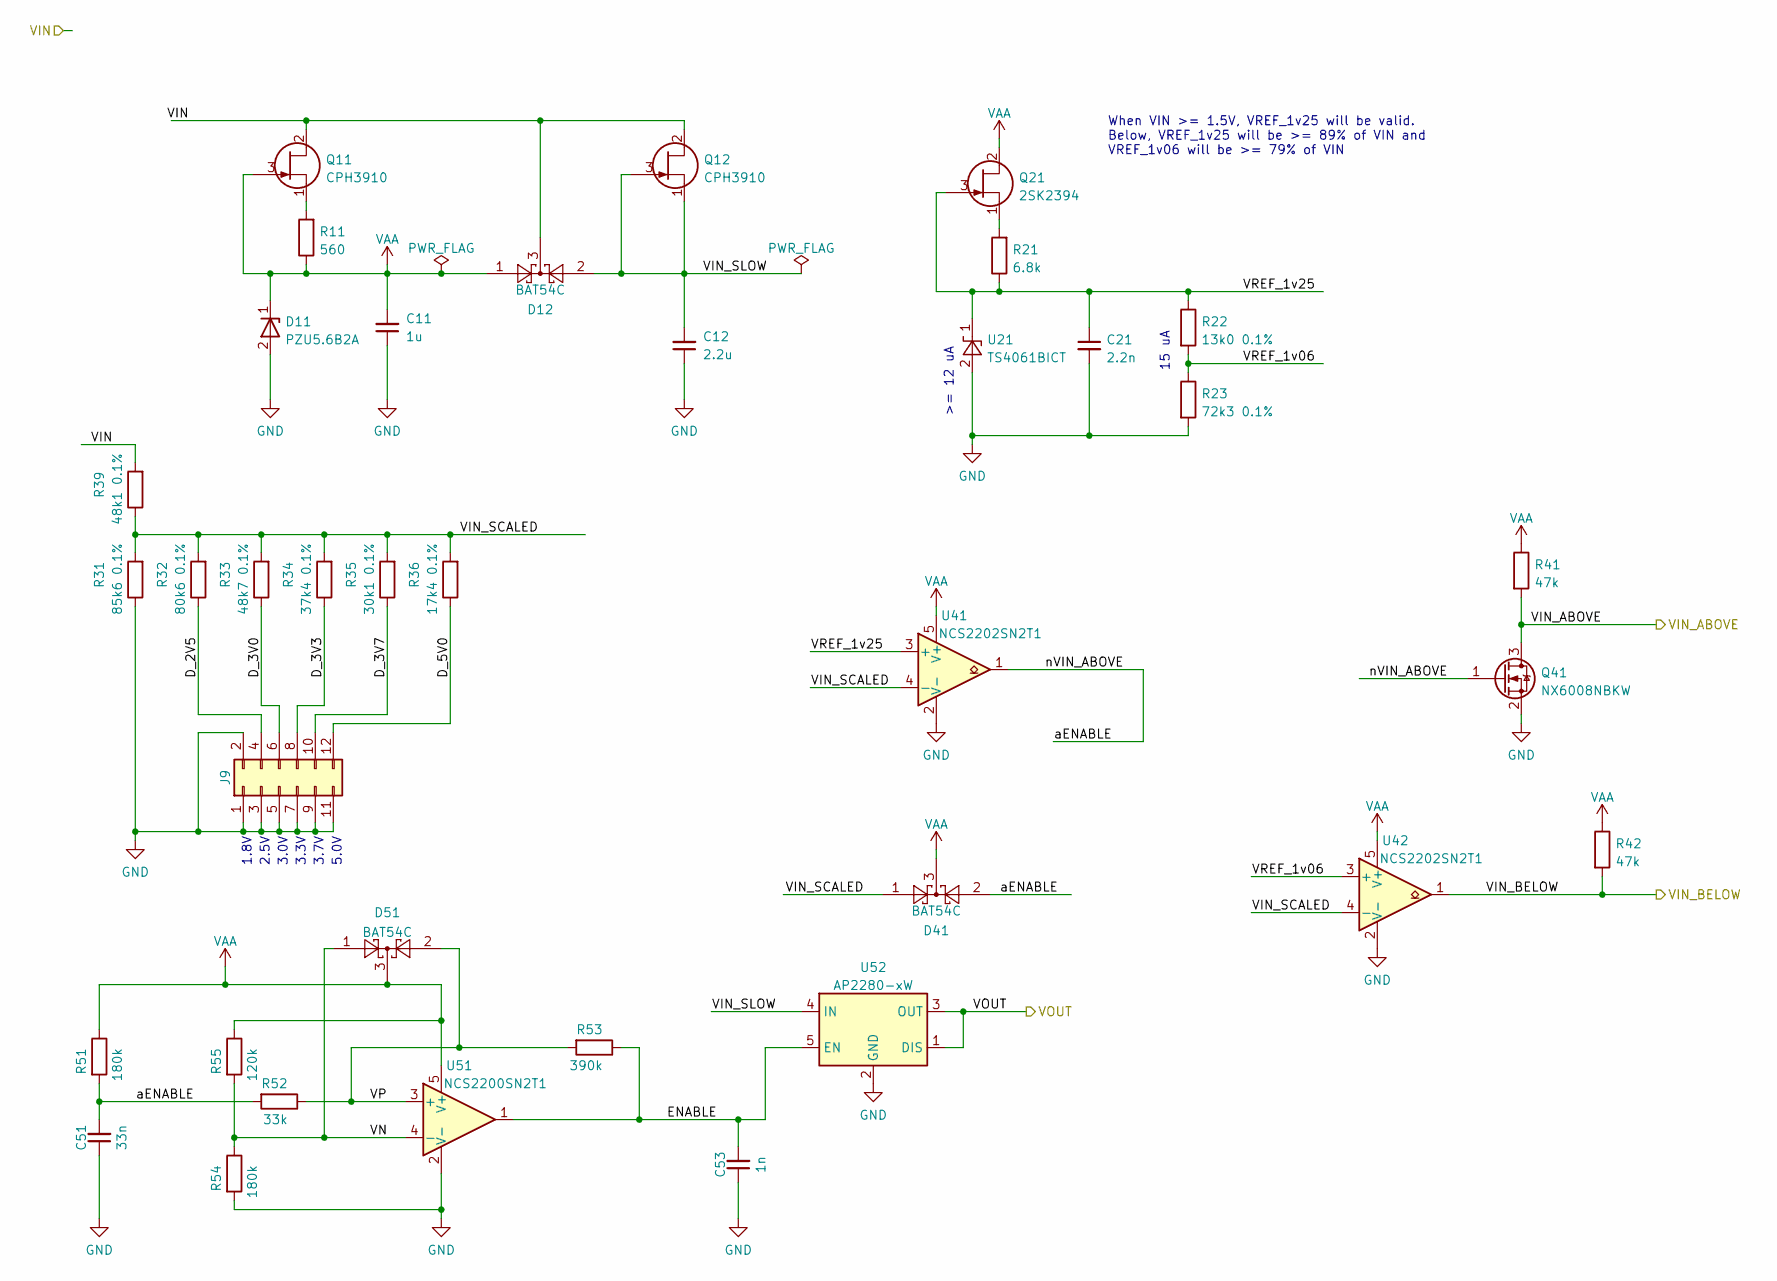
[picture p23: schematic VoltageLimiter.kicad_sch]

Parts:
C11: 1u; C_0805_2012Metric_Pad1.18x1.45mm_HandSolder
C12: 2.2u; C_0805_2012Metric_Pad1.18x1.45mm_HandSolder
C21: 2.2n; C_0805_2012Metric_Pad1.18x1.45mm_HandSolder
C51: 33n; C_0805_2012Metric_Pad1.18x1.45mm_HandSolder
C53: 1n; C_0805_2012Metric_Pad1.18x1.45mm_HandSolder
D11: PZU5.6B2A; D_SOD-323_HandSoldering
D12, D41, D51: BAT54C; SOT-23_Handsoldering
J9: PinHeader_2x06_P2.54mm_Horizontal_Jumper
Q11, Q12: CPH3910; SOT-23_Handsoldering
Q21: 2SK2394; SOT-23_Handsoldering
Q41: NX6008NBKW; SOT-323_SC-70_Handsoldering
R11: 560; R_0805_2012Metric_Pad1.20x1.40mm_HandSolder
R21: 6.8k; R_0805_2012Metric_Pad1.20x1.40mm_HandSolder
R22: 13k0 0.1%; R_0805_2012Metric_Pad1.20x1.40mm_HandSolder
R23: 72k3 0.1%; R_0805_2012Metric_Pad1.20x1.40mm_HandSolder
R31: 85k6 0.1%; R_0805_2012Metric_Pad1.20x1.40mm_HandSolder
R32: 80k6 0.1%; R_0805_2012Metric_Pad1.20x1.40mm_HandSolder
R33: 48k7 0.1%; R_0805_2012Metric_Pad1.20x1.40mm_HandSolder
R34: 37k4 0.1%; R_0805_2012Metric_Pad1.20x1.40mm_HandSolder
R35: 30k1 0.1%; R_0805_2012Metric_Pad1.20x1.40mm_HandSolder
R36: 17k4 0.1%; R_0805_2012Metric_Pad1.20x1.40mm_HandSolder
R39: 48k1 0.1%; R_0805_2012Metric_Pad1.20x1.40mm_HandSolder
R41, R42: 47k; R_0805_2012Metric_Pad1.20x1.40mm_HandSolder
R51, R54: 180k; R_0805_2012Metric_Pad1.20x1.40mm_HandSolder
R52: 33k; R_0805_2012Metric_Pad1.20x1.40mm_HandSolder
R53: 390k; R_0805_2012Metric_Pad1.20x1.40mm_HandSolder
R55: 120k; R_0805_2012Metric_Pad1.20x1.40mm_HandSolder
U21: TS4061BICT; SOT-323_SC-70_Handsoldering
U41, U42: NCS2202SN2T1; SOT-23-5_HandSoldering
U51: NCS2200SN2T1; SOT-23-5_HandSoldering
U52: AP2280-xW; SOT-23-5_HandSoldering

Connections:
/VIN: D12.3, Q11.2 (D), Q12.2 (D), R39.2; also elsewhere on the board
/VIN_ABOVE: Q41.3 (D), R41.2; also elsewhere on the board
/VIN_BELOW: R42.2, U42.1; also elsewhere on the board
/VoltageLimiter/D_2V5: J9.4, R32.1
/VoltageLimiter/D_3V0: J9.6, R33.1
/VoltageLimiter/D_3V3: J9.8, R34.1
/VoltageLimiter/D_3V7: J9.10, R35.1
/VoltageLimiter/D_5V0: J9.12, R36.1
/VoltageLimiter/ENABLE: C53.2, R53.1, U51.1, U52.5 (EN)
/VoltageLimiter/VIN_SCALED: D41.1, R31.2, R32.2, R33.2, R34.2, R35.2, R36.2, R39.1, U41.4 (-), U42.4 (-)
/VoltageLimiter/VIN_SLOW: C12.2, D12.2, Q12.1 (S), Q12.3 (G), U52.4 (IN)
/VoltageLimiter/VN: D51.1, R54.1, R55.2, U51.4 (-)
/VoltageLimiter/VOUT: U52.1 (DIS), U52.3 (OUT); also elsewhere on the board
/VoltageLimiter/VP: D51.2, R52.1, R53.2, U51.3 (+)
/VoltageLimiter/VREF_1v06: R22.2, R23.1, U42.3 (+)
/VoltageLimiter/VREF_1v25: C21.1, Q21.3 (G), R21.1, R22.1, U21.1 (K), U41.3 (+)
/VoltageLimiter/aENABLE: C51.2, D41.2, Q41.1 (G), R51.2, R52.2, U41.1
GND: C11.1, C12.1, C21.2, C51.1, C53.1, D11.2 (A), J9.1, J9.2, J9.3, J9.5, J9.7, J9.9, J9.11, Q41.2 (S), R23.2, R31.1, R54.2, U21.2 (A), U41.2 (V-), U42.2 (V-), U51.2 (V-), U52.2 (GND); also elsewhere on the board
unnamed: Q11.1 (S), R11.2
unnamed: Q21.1 (S), R21.2
VAA: C11.2, D11.1 (K), D12.1, D41.3, D51.3, Q11.3 (G), Q21.2 (D), R11.1, R41.1, R42.1, R51.1, R55.1, U41.5 (V+), U42.5 (V+), U51.5 (V+)

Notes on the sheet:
15 uA
3.7V
When VIN >= 1.5V, VREF_1v25 will be valid. Below, VREF_1v25 will be >= 89% of VIN and VREF_1v06 will be >= 79% of VIN
2.5V
3.0V
1.8V
>= 12 uA
5.0V
3.3V

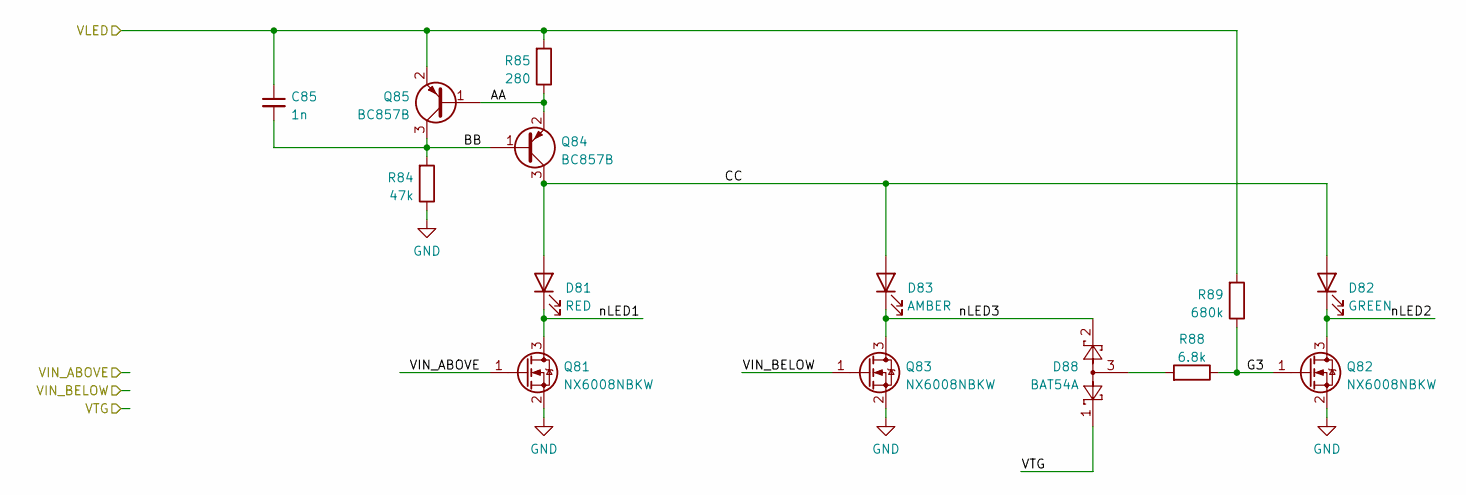
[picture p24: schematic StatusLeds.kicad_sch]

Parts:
C85: 1n; C_0805_2012Metric_Pad1.18x1.45mm_HandSolder
D81: RED; LED_0805_2012Metric_Pad1.15x1.40mm_HandSolder
D82: GREEN; LED_0805_2012Metric_Pad1.15x1.40mm_HandSolder
D83: AMBER; LED_0805_2012Metric_Pad1.15x1.40mm_HandSolder
D88: BAT54A; SOT-23_Handsoldering
Q81, Q82, Q83: NX6008NBKW; SOT-323_SC-70_Handsoldering
Q84, Q85: BC857B; SOT-23_Handsoldering
R84: 47k; R_0805_2012Metric_Pad1.20x1.40mm_HandSolder
R85: 280; R_0805_2012Metric_Pad1.20x1.40mm_HandSolder
R88: 6.8k; R_0805_2012Metric_Pad1.20x1.40mm_HandSolder
R89: 680k; R_0805_2012Metric_Pad1.20x1.40mm_HandSolder

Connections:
/StatusLeds/AA: Q84.2 (E), Q85.1 (B), R85.1
/StatusLeds/BB: C85.2, Q84.1 (B), Q85.3 (C), R84.2
/StatusLeds/CC: D81.2 (A), D82.2 (A), D83.2 (A), Q84.3 (C)
/StatusLeds/G3: Q82.1 (G), R88.1, R89.1
/StatusLeds/nLED1: D81.1 (K), Q81.3 (D)
/StatusLeds/nLED2: D82.1 (K), Q82.3 (D)
/StatusLeds/nLED3: D83.1 (K), D88.2, Q83.3 (D)
/VIN_ABOVE: Q81.1 (G); also elsewhere on the board
/VIN_BELOW: Q83.1 (G); also elsewhere on the board
/VLED: C85.1, Q85.2 (E), R85.2, R89.2; also elsewhere on the board
/VTG: D88.1; also elsewhere on the board
GND: Q81.2 (S), Q82.2 (S), Q83.2 (S), R84.1; also elsewhere on the board
unnamed: D88.3, R88.2

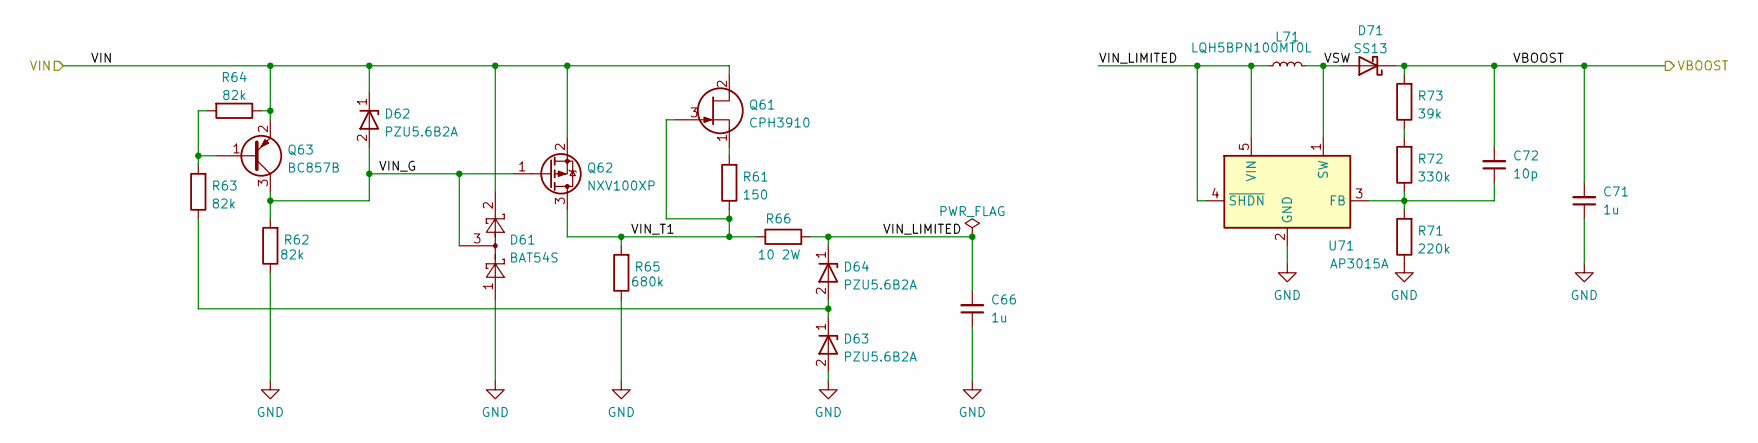
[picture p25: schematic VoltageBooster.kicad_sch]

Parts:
C66, C71: 1u; C_0805_2012Metric_Pad1.18x1.45mm_HandSolder
C72: 10p; C_0805_2012Metric_Pad1.18x1.45mm_HandSolder
D61: BAT54S; SOT-23_Handsoldering
D62, D63, D64: PZU5.6B2A; D_SOD-323_HandSoldering
D71: SS13; D_SMA+SMP_Handsoldering
L71: LQH5BPN100MT0L; L_6.5x6.5_H4.5
Q61: CPH3910; SOT-23_Handsoldering
Q62: NXV100XP; SOT-23_Handsoldering
Q63: BC857B; SOT-23_Handsoldering
R61: 150; R_0805_2012Metric_Pad1.20x1.40mm_HandSolder
R62, R63, R64: 82k; R_0805_2012Metric_Pad1.20x1.40mm_HandSolder
R65: 680k; R_0805_2012Metric_Pad1.20x1.40mm_HandSolder
R66: 10 2W; R_2512_6332Metric_Pad1.40x3.35mm_HandSolder
R71: 220k; R_0805_2012Metric_Pad1.20x1.40mm_HandSolder
R72: 330k; R_0805_2012Metric_Pad1.20x1.40mm_HandSolder
R73: 39k; R_0805_2012Metric_Pad1.20x1.40mm_HandSolder
U71: AP3015A; SOT-23-5_HandSoldering

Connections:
/VIN: D61.2, D62.1 (K), Q61.2 (D), Q62.2 (S), Q63.2 (E), R64.1; also elsewhere on the board
/VoltageBooster/VBOOST: C71.2, C72.2, D71.1 (K), R73.2; also elsewhere on the board
/VoltageBooster/VIN_G: D61.3, D62.2 (A), Q62.1 (G), Q63.3 (C), R62.2
/VoltageBooster/VIN_LIMITED: C66.2, D64.1 (K), L71.1, R66.2, U71.4 (~SHDN), U71.5 (VIN)
/VoltageBooster/VIN_T1: Q61.3 (G), Q62.3 (D), R61.1, R65.2, R66.1
/VoltageBooster/VSW: D71.2 (A), L71.2, U71.1 (SW)
GND: C66.1, C71.1, D61.1, D63.2 (A), R62.1, R65.1, R71.1, U71.2 (GND); also elsewhere on the board
unnamed: C72.1, R71.2, R72.1, U71.3 (FB)
unnamed: D63.1 (K), D64.2 (A), R63.1
unnamed: Q61.1 (S), R61.2
unnamed: Q63.1 (B), R63.2, R64.2
unnamed: R72.2, R73.1

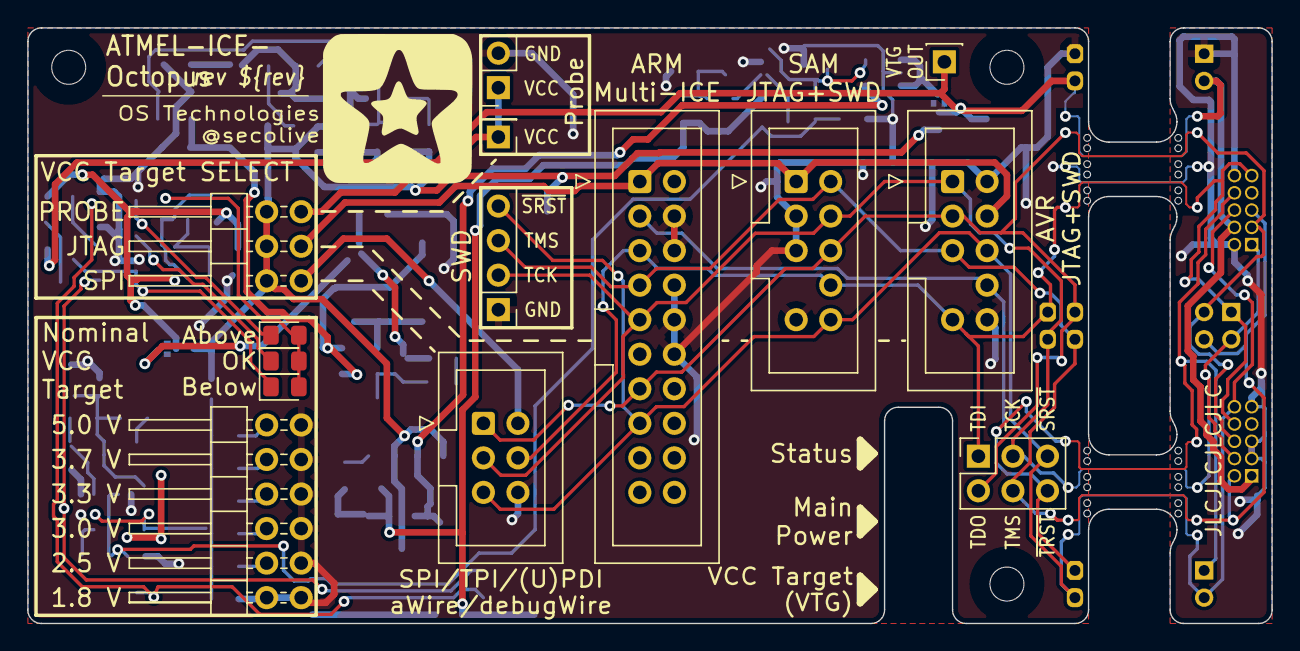
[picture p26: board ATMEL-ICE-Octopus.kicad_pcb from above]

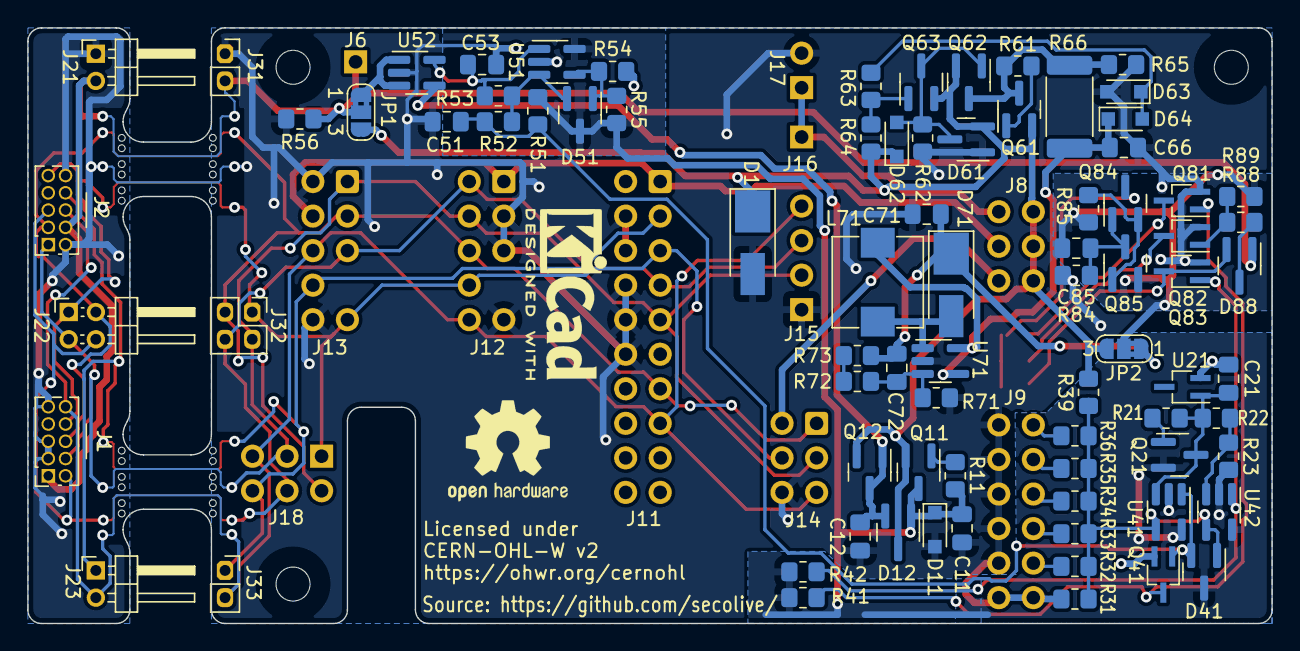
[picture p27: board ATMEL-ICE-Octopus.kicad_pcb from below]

Board: 2 copper layers, 91.5 x 43.8 mm, 105 parts (83 on the bottom side), 50 nets.

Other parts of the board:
G1: LOGO
G1#2: OpenHardware Logo; OSHW-Logo2_9.8x8mm_SilkScreen
G3: KiCad logo; KiCad-Logo2_5mm_SilkScreen

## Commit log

2022-06-14 ATMEL-ICE-Octopus-backups: rev A0
    [ATMEL-ICE-Octopus-B_Cu.gbr, ATMEL-ICE-Octopus-B_Mask.gbr, ATMEL-ICE-Octopus-B_Silkscreen.gbr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]
2022-06-14 JTAG-MINI_ADAPTER: rev A0
    [JTAG-MINI-ADAPTER-B_Cu.gbr, JTAG-MINI-ADAPTER-B_Mask.gbr, JTAG-MINI-ADAPTER-B_Silkscreen.gbr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]
2022-06-21 ATMEL-ICE-Octopus: rev A1 - add OHL license and use kibot
    [ATMEL-ICE-Octopus-bom.csv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]
2022-06-21 ATMEL-ICE-Octopus-Back: rev A1 - add OHL license and use kibot
    [ATMEL-ICE-Octopus-Back-bom.csv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]
2022-06-21 JTAG-MINI-ADAPTER: rev A1 - add OHL license and use kibot
    [JTAG-MINI-ADAPTER-bom.csv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]
2022-12-22 ATMEL-ICE-Octopus: rev B5
    [ATMEL-ICE-Octopus-B_Cu.gbr, ATMEL-ICE-Octopus-B_Mask.gbr, ATMEL-ICE-Octopus-B_Silkscreen.gbr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]
2023-01-09 ATMEL-ICE-Octopus: rev B6
    [ATMEL-ICE-Octopus-bom.csv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]

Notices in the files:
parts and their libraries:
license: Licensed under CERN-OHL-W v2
